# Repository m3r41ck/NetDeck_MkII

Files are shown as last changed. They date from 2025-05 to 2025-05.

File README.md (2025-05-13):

# Custom Macropad Project

## Project Overview
This is a custom macropad I designed, assembled, and programmed as a personal project to strengthen my hardware and embedded systems skills.

## Features
- PCB design (created using KiCad)
- Firmware flashing QMK
- Hardware assembly and soldering

## Current Status
✅ Moved from breadboard to custom PCB.  
🔜 Designing custom enclosure and expanding firmware functionality.

## Lessons Learned
- Double-check PCB traces before ordering!
- How to debug hardware connections
- How to flash and customize firmware

## Next Steps
- Design and 3D-print an enclosure
- Add support for additional macros and features

## Images



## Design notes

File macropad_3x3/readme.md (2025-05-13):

# macropad_3x3

macropad_3x3

*A short description of the keyboard/project*

* Keyboard Maintainer: [Merrick](https://github.com/m3r41ck)
* Hardware Supported: *The PCBs, controllers supported*
* Hardware Availability: *Links to where you can find this hardware*

Make example for this keyboard (after setting up your build environment):

    make macropad_3x3:default

Flashing example for this keyboard:

    make macropad_3x3:default:flash

See the [build environment setup](https://docs.qmk.fm/#/getting_started_build_tools) and the [make instructions](https://docs.qmk.fm/#/getting_started_make_guide) for more information. Brand new to QMK? Start with our [Complete Newbs Guide](https://docs.qmk.fm/#/newbs).

## Bootloader

Enter the bootloader in 3 ways:

* **Bootmagic reset**: Hold down the key at (0,0) in the matrix (usually the top left key or Escape) and plug in the keyboard
* **Physical reset button**: Briefly press the button on the back of the PCB - some may have pads you must short instead
* **Keycode in layout**: Press the key mapped to `QK_BOOT` if it is available

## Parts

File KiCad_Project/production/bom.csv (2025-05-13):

Designator | Footprint | Quantity | Value | LCSC Part #
D1, D2, D3, D4 | Diode_DO-35 | 4 | Diode
S1, S2, S3, S4 | MX_PCB_1.00u | 4 | Keyswitch
U1 | Arduino_Pro_Micro | 1 | Arduino_Pro_Micro

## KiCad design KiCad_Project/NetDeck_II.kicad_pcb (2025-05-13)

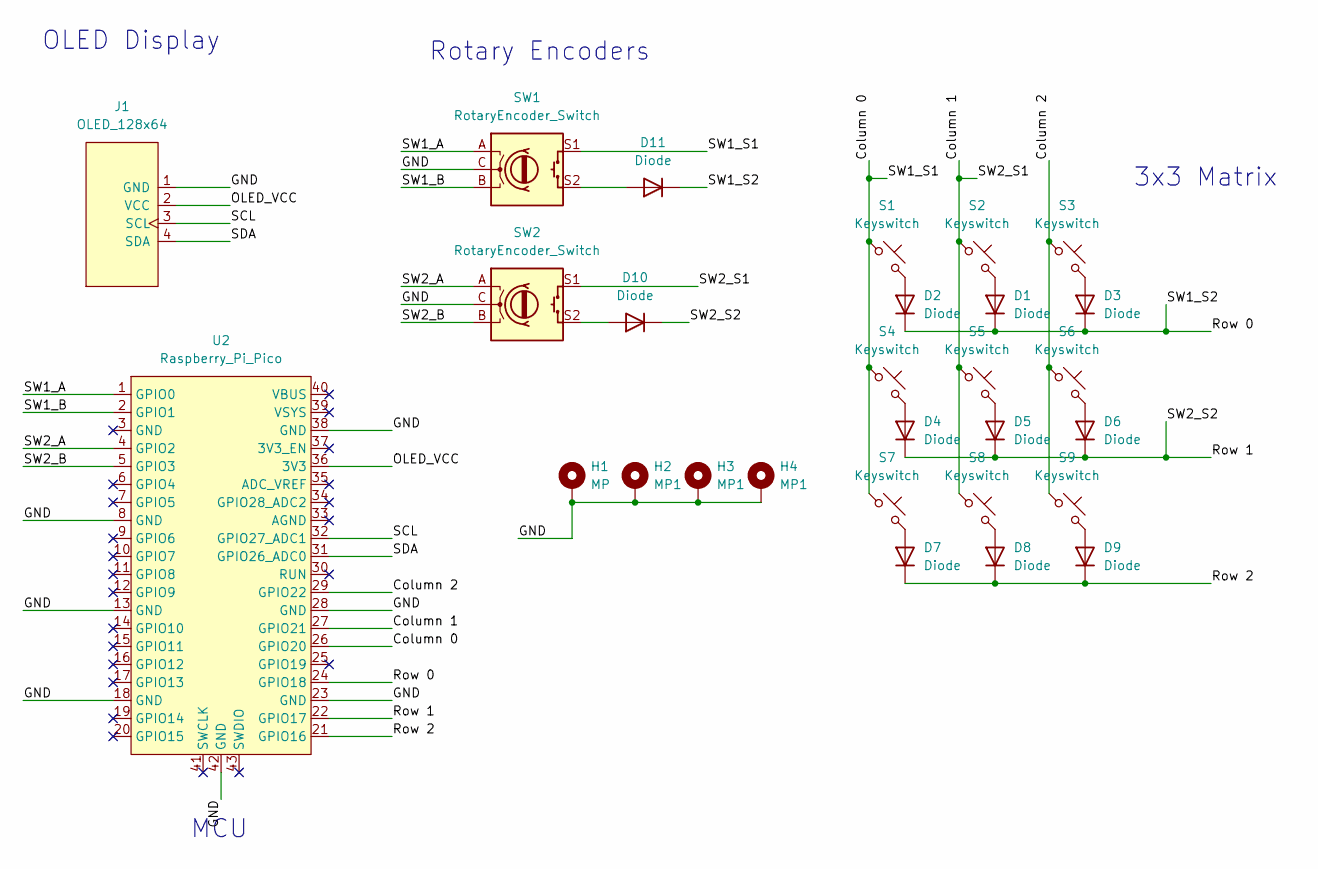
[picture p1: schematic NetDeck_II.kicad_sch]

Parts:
D1, D2, D3, D4, D5, D6, D7, D8, D9, D10, D11: Diode; Diode_DO-35
H1: MP; MountingHole_3.5mm_Pad_Via
H2, H3, H4: MP1; MountingHole_3.5mm_Pad_Via
J1: OLED_128x64
S1, S2, S3, S4, S5, S6, S7, S8, S9: Keyswitch; MX_PCB_1.00u
SW1, SW2: RotaryEncoder_Switch; RotaryEncoder_Alps_EC11E-Switch_Vertical_H20mm
U2: Raspberry_Pi_Pico

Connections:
/Column 0: S1.1, S4.1, S7.1, SW1.S1, U2.26 (GPIO20)
/Column 1: S2.1, S5.1, S8.1, SW2.S1, U2.27 (GPIO21)
/Column 2: S3.1, S6.1, S9.1, U2.29 (GPIO22)
/GND: H1.1, H2.1, H3.1, H4.1, J1.1 (GND), SW1.C, SW2.C, U2.8 (GND), U2.13 (GND), U2.18 (GND), U2.23 (GND), U2.28 (GND), U2.38 (GND), U2.42 (GND)
/OLED_VCC: J1.2 (VCC), U2.36 (3V3)
/Row 0: D1.1 (K), D2.1 (K), D3.1 (K), D11.1 (K), U2.24 (GPIO18)
/Row 1: D4.1 (K), D5.1 (K), D6.1 (K), D10.1 (K), U2.22 (GPIO17)
/Row 2: D7.1 (K), D8.1 (K), D9.1 (K), U2.21 (GPIO16)
/SCL: J1.3 (SCL), U2.32 (GPIO27_ADC1)
/SDA: J1.4 (SDA), U2.31 (GPIO26_ADC0)
/SW1_A: SW1.A, U2.1 (GPIO0)
/SW1_B: SW1.B, U2.2 (GPIO1)
/SW2_A: SW2.A, U2.4 (GPIO2)
/SW2_B: SW2.B, U2.5 (GPIO3)
unnamed: D1.2 (A), S2.2
unnamed: D2.2 (A), S1.2
unnamed: D3.2 (A), S3.2
unnamed: D4.2 (A), S4.2
unnamed: D5.2 (A), S5.2
unnamed: D6.2 (A), S6.2
unnamed: D7.2 (A), S7.2
unnamed: D8.2 (A), S8.2
unnamed: D9.2 (A), S9.2
unnamed: D10.2 (A), SW2.S2
unnamed: D11.2 (A), SW1.S2

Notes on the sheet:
3x3 Matrix
MCU
Rotary Encoders
OLED Display

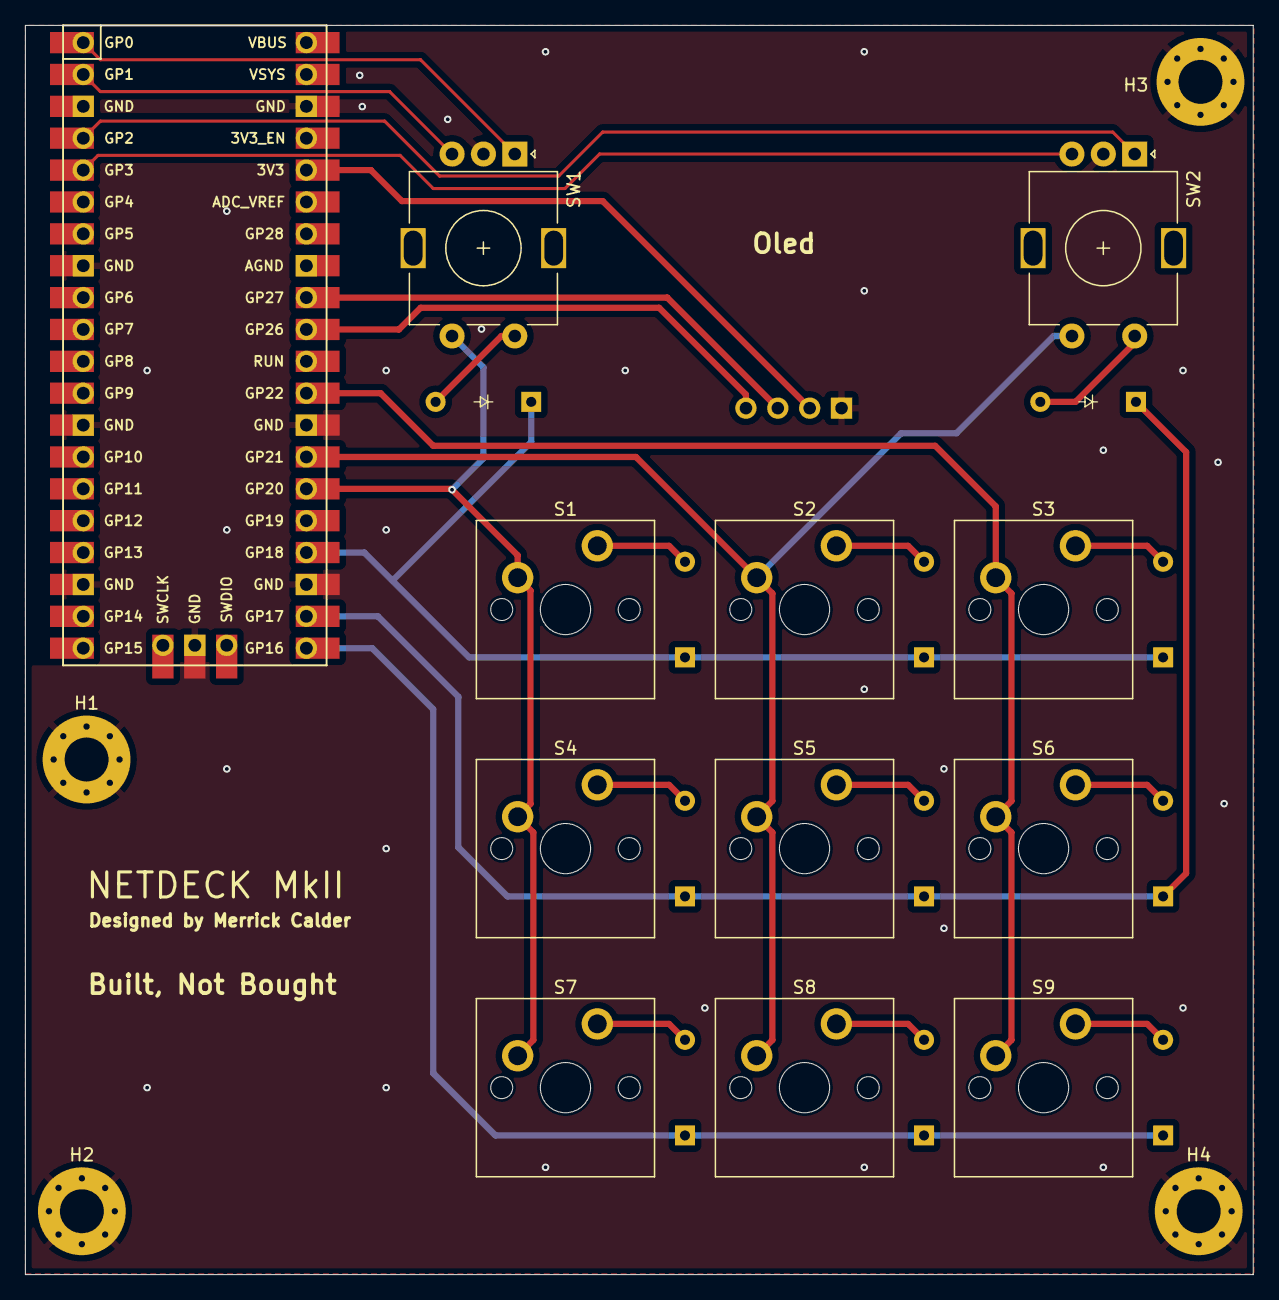
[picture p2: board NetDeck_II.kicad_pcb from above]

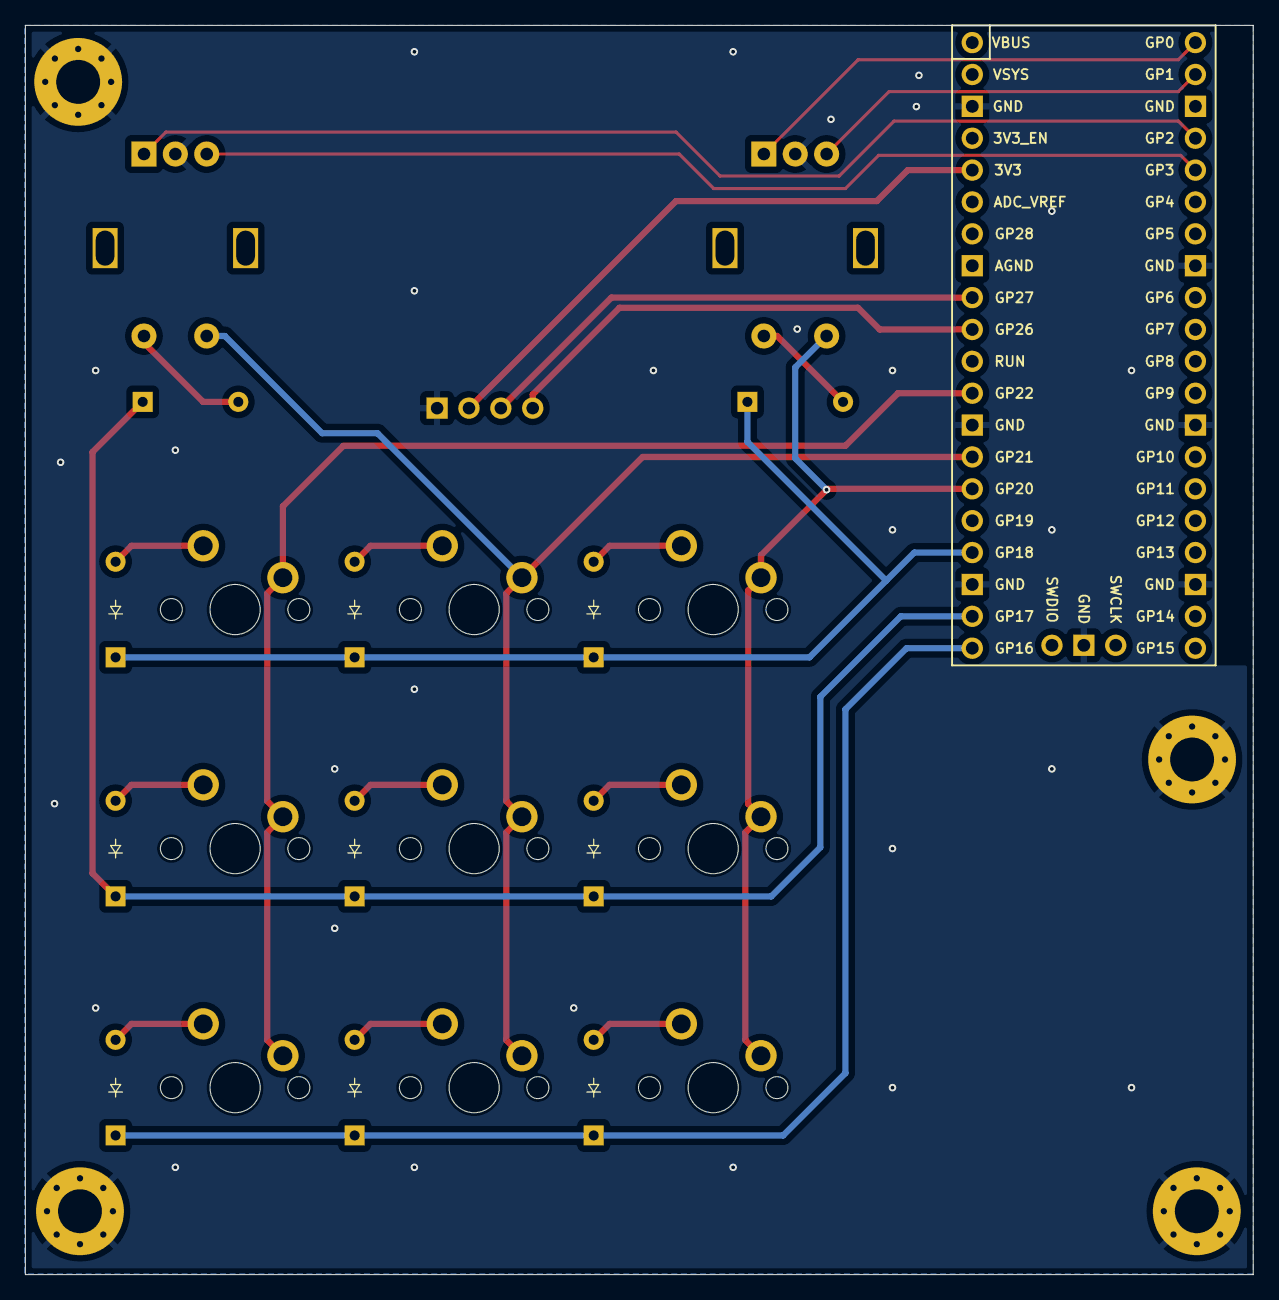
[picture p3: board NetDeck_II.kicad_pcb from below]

Board: 2 copper layers, 97.8 x 99.5 mm, 28 parts (9 on the bottom side), 25 nets.

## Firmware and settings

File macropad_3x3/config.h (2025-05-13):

#pragma once

// OLED DRIVER CONFIG
#define OLED_DRIVER_ENABLE
#define OLED_DISPLAY_ADDRESS 0x3C
#define I2C_DRIVER  I2CD1
#define I2C1_SCL_PIN GP27
#define I2C1_SDA_PIN GP26
#define OLED_DISPLAY_128X64
#define OLED_TIMEOUT 60000  // 60 seconds
// #define OLED_ROTATION OLED_ROTATION_180  // Rotate display 180 degrees

// ENCODER CONFIG
#define ENCODER_A_PINS {GP0, GP2}
#define ENCODER_B_PINS {GP1, GP3}

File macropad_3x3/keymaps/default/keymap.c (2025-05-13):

// Copyright 2023 QMK
// SPDX-License-Identifier: GPL-2.0-or-later

#include QMK_KEYBOARD_H


const uint16_t PROGMEM keymaps[][MATRIX_ROWS][MATRIX_COLS] = {
    /*
     * ┌────────────┬────────────┬────────────┐
     * │ Prev Track │ Play/Pause │ Next Track │
     * ├────────────┼────────────┼────────────┤
     * │     4      │     5      │      6     │
     * ├────────────┼────────────┼────────────┤
     * │     1      │     2      │      3     │
     * └────────────┴────────────┴────────────┘
     */
     [0] = LAYOUT(
      KC_MPRV,   KC_MPLY, KC_MNXT,
      _______,   KC_MUTE, _______,
      _______,   _______, _______
  )
};

#ifdef ENCODER_MAP_ENABLE
const uint16_t PROGMEM encoder_map[][NUM_ENCODERS][NUM_DIRECTIONS] = {
    [0] = { ENCODER_CCW_CW(KC_VOLU, KC_VOLD)}
};
#endif

#ifdef OLED_ENABLE
oled_rotation_t oled_init_user(oled_rotation_t rotation) {
    return OLED_ROTATION_180;
}

bool oled_task_user(void) {
    oled_set_cursor(0, 1);

    oled_write("NETDECK Mk II", false);
    return false;
}
#endif
